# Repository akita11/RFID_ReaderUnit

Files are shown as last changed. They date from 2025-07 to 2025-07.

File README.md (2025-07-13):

# RFID Reader UNIT

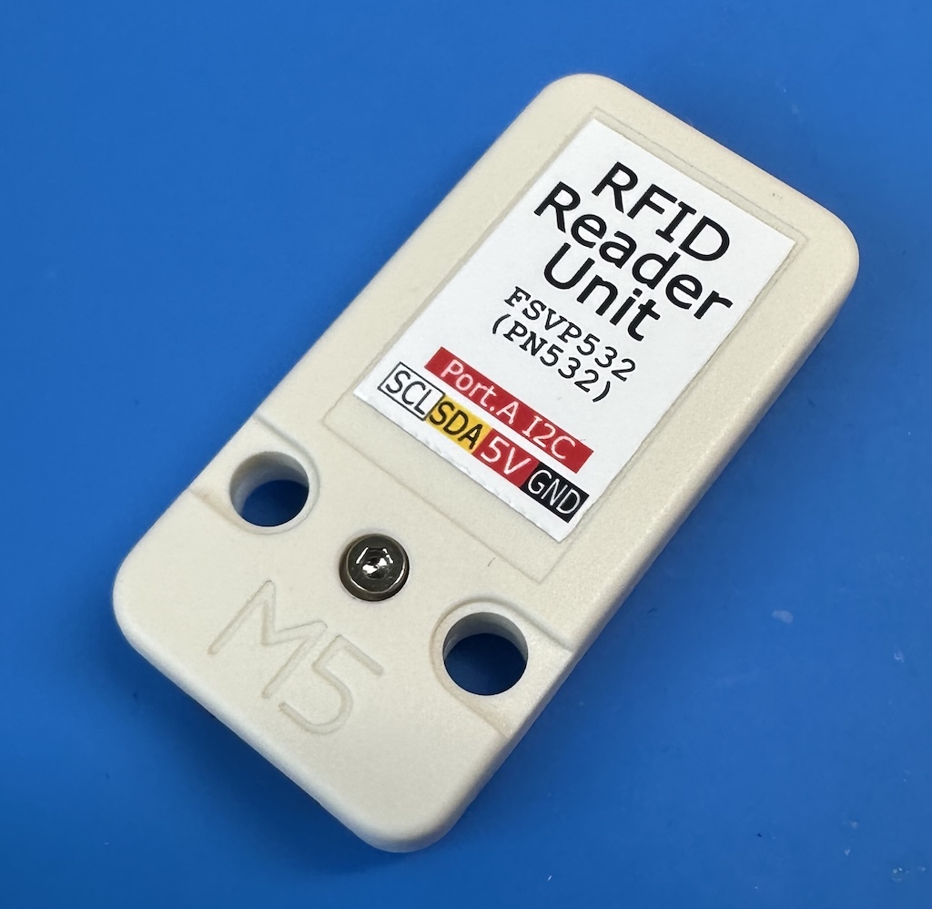
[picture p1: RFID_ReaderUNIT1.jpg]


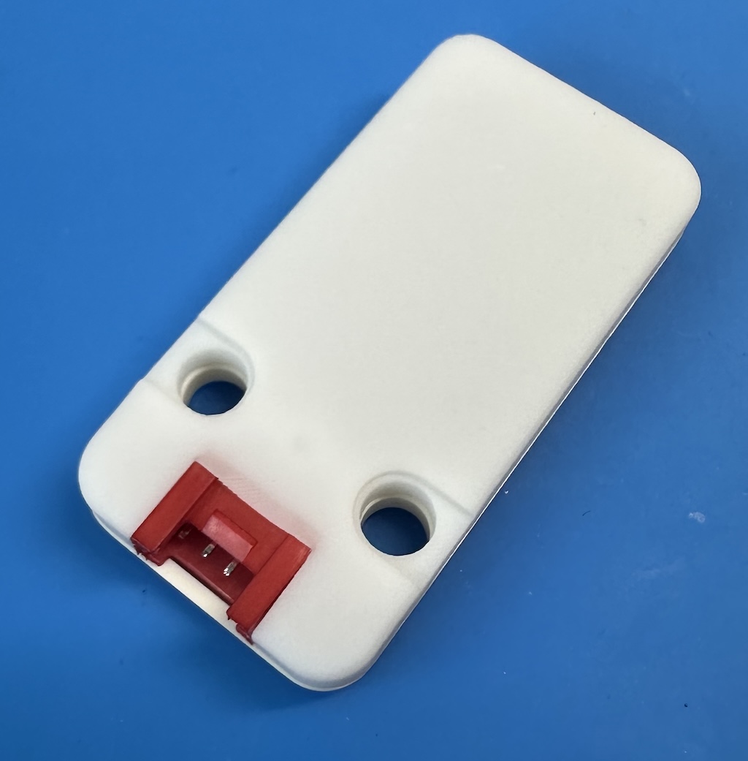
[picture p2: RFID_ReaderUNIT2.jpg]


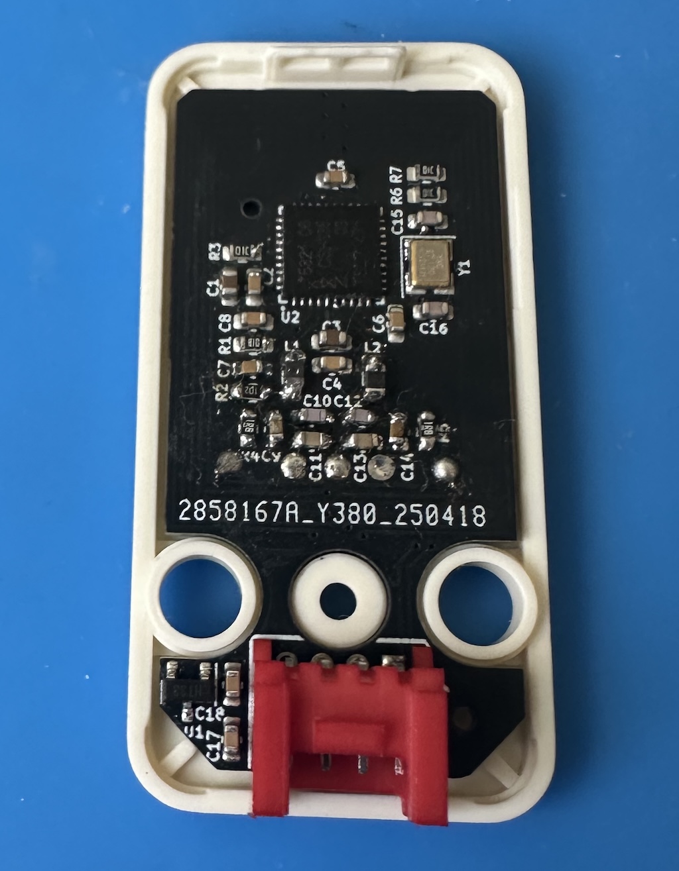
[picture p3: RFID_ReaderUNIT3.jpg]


## 内容

Felica対応のRFIDリーダICのForSinVe社FSVP532（よく使われるNXP社のPN532互換）を使ったRFIDリーダです。M5Stack等のマイコンとGroveケーブル（I2C通信）で接続して、FelicaやNFCを読み書きすることができます。PN532用のライブラリで使用することができます。（UIFlow用のカスタムブロックを用意する予定）

## 使い方

ArduinoやM5Stack等のマイコンにGroveポート経由でI2C接続します。
ソフトウエアはは、PN532用のもの使用します。
PN532用のソフトウエアとしては、Arduino用ライブラリがいくつかあります。
例えばAdafruitやSeeedのものがありますが、Felicaを読み出す関数とサンプルプログラムは提供されていないようです。
[こちら](https://github.com/elechouse/PN532)のライブラリは、これらを元にしたもの（fork）で、Felica関連の関数やサンプルプログラムも含まれているので、こちらを利用するとよいでしょう。
ただしサンプルプログラムは、PN532をI2C接続して使用する設定にはなっていませんので、冒頭の以下の「※」のところを変更します。これにより、I2C接続で使用できるようになります。
```FeliCa_card_read.pde
#if 0 // <--- ※original:1
  #include <SPI.h>
  #include <PN532_SPI.h>
  #include <PN532.h>

PN532_SPI pn532spi(SPI, 10);
PN532 nfc(pn532spi);
#elif 0
  #include <PN532_HSU.h>
  #include <PN532.h>

PN532_HSU pn532hsu(Serial1);
PN532 nfc(pn532hsu);
#else
  #include <Wire.h>
  #include <PN532_I2C.h>
  #include <PN532.h>

PN532_I2C pn532i2c(Wire);
PN532 nfc(pn532i2c);
#endif
```

なお稀に電源ON時のリセット(POR; Power On Reset)が効かず、初期化に失敗することがあるようです。その場合は、電源を入れなおしてください。

## 電波関連法令の規格について

RFIDリーダは無線通信機器ではなく「誘導式読み書き通信設備」というカテゴリに含まれます。
そのため、無線通信機器の認証に必要な、いわゆる技適は無関係です。
（[法令関連の情報まとめの例](http://dsas.blog.klab.org/archives/2018-04/52291765.html)）
「誘導式読み書き通信設備」は、法令の要件（電界強度の規定、または総務大臣型式指定）を満たせば許可不要で使用することができる、と規定されています。
その要件のうちの「電界強度の規定」（3mの距離における電界強度が500μV/m（≒54dBμV/m）以下）を満たしていることの表示方法については明記されていません。
そのため、測定条件や測定データ等の客観的なデータを示すことで、その要件を満たす、というのが一般的な解釈と考えています。
例えば（株）スイッチサイエンスで販売している[RFID2 Unit](https://www.switch-science.com/products/8301)では、電界強度の測定法・測定結果を示し、それに基づいて規定を満たしている、と表示しています。

このRFID Reader UNITの電界強度測定の測定法・測定結果は「RFID_ReaderUNIT_meaasure.pdf」に記載の通り、これは法令の要件である電界強度の規定を満たしています。
なお今回のアンテナ設計手順をまとめた資料は、AntennaDesign/以下にあります。

## Author

Junichi Akita (@akita11) / akita@ifdl.jp

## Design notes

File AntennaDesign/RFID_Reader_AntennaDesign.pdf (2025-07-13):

## RFID Reader Unit アンテナ設計と特性測定の記録

250710 akita11(akita@ifdl.jp)

⽬標
Felica も読める RFID リーダをつくって販売したい（M5Stack の RFID2 Unit は Felica は対応していな い）。AliExp などで売っているものもある（Arduino ⽤ライブラリなどもある）が、⽇本の電波法令の基 準を満たしているかが表⽰されていない。また形状も M5Stack の Unit サイズにしたい。 そこで、Felica を読める IC を使って Unit サイズのものを設計し（マイコンとの通信は I2C）、⽇本の電 波関連法令の基準を満たしていることを⽰したうえで販売したい。
なお 13.56MHz RFID の規格が歴史的経緯から複雑だが、⼤まかには以下の通り。なおよく使われている NXP の PN532 は、ISO/IEC14443-3 TypeA/B, MIFARE, Felica に対応しているので、これを使うことに する（正確にはその互換品の Forsinve 社 FSVP532 を使う）。
l ISO/IEC14443-3
Ø Type A: MIFARE など（NFC-A とも呼ばれる）
Ø Type B: マイナンバーカード、⽇本のパスポートなど（NFC-B とも呼ばれる）
l MIFARE：ISO 14443 Type A を拡張した NXP 独⾃規格。⽇本の交通系 IC カード。Classic, DESFire, Ultralight など複数シリーズが存在。
l FeliCa：ソニー独⾃規格（ISO 18092 準拠）、楽天 Edy、WAON、交通系 IC カードなど。（NFC−F とも呼ばれる）

RFID リーダのアンテナ設計の⼀般論
⼀次情報として、使う NXP 社から提供されている、PN532 のアプリケーションノート AN1445(”Antenna design guide for MFRC52x, PN51x and PN53x”)からはじめる。

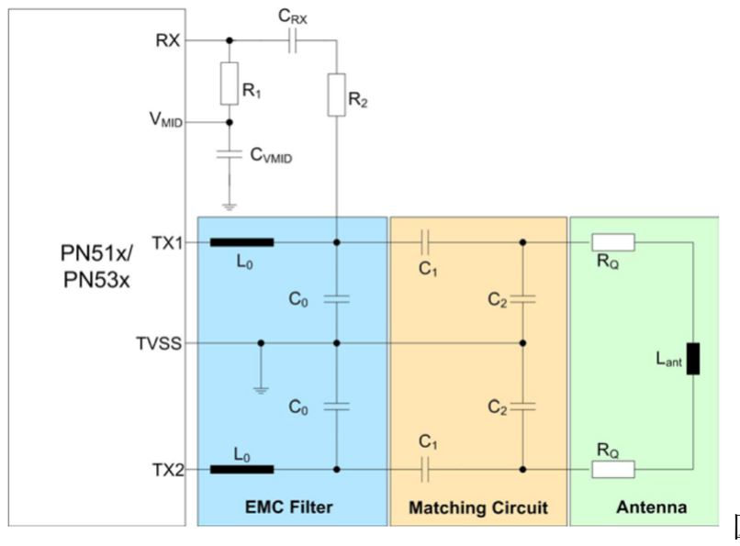
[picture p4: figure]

図 1
アンテナ部分は、EMS Filter 部、Matching Circuit 部、Antenna 部、からなる。
Antenna 部分は、基板パターンをぐるぐる巻いた配線パターン（ループアンテナ）で、まずはこれを設計

する。

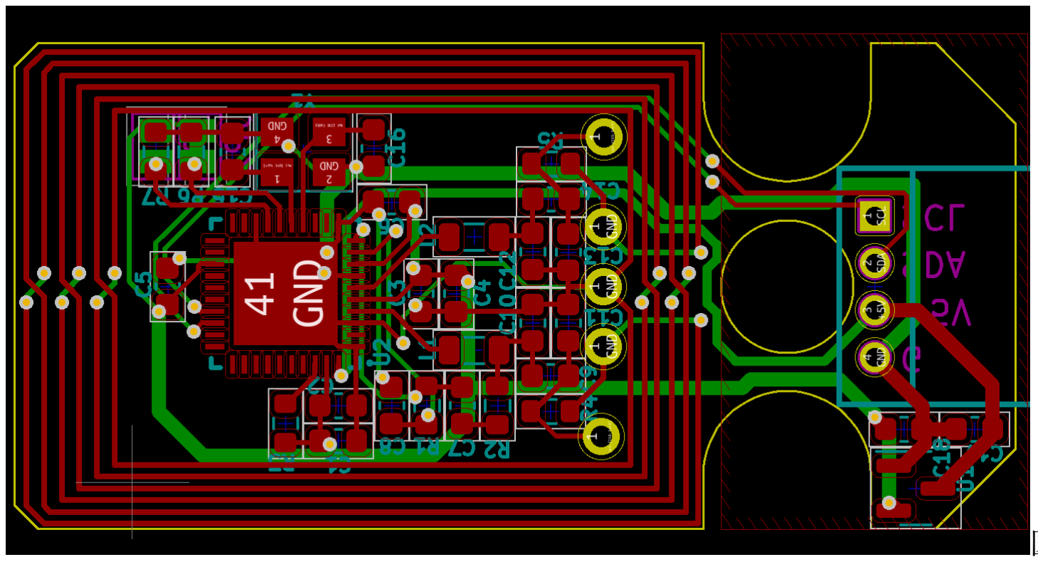
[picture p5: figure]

図 2
今回は、いろいろな事例を参考に、図 2 のような基板パターンを設計した。左側の外周部を 6 回まわっ ている配線パターンがインダクタになる。なお基板の素材や厚さ、配線幅や巻数からインダクタを計算 するツールもあるが、正直、その精度がどの程度あてになるかわからないので、今回は、まずは基板パタ ーンを設計し、それを実測することにした。
この基板を製造し、そのインピーダンス（等価回路）を計測し、それにあわせて図 1 の EMC Filer 部と Matching Circuit 部の素⼦値を決めていく。その後、計算（シミュレーション）と実測を⾏き来しながら、 ⽬的の特性になるような素⼦値を決定する。
なおこの AN1445 は、けっこう途中が省略されていて（例えば C1,C2 を変えるとどう特性が変わるか、 など、また L0 を 560nH で決め打ちしている（後述のようにこれは変更しないとマッチングがとれない）、 など）、こちらの別の RFID Reader ⽤ IC のアプリケーションノートを読むことで理解が深まり、マッチ ング調整の⽅針の⾒通しを⽴てることができた。
l AN12549（”PN5190 antenna design guide”）
l AN13219（”PN7160 antenna design and matching guide”）
また素⼦値の計算はまあまあ⾯倒な式で、それを計算するための Excel シート（AN144411.xls）が AN1445 で紹介されて提供されているので、それを使ってもいいと思う。ただ個⼈的には、これの計算過程に出て くる等価回路が 2 種類あって、並列等価回路の Ra の計算・求め⽅がわからなかったため、結果としてあ まり使わなかった。逆に今回は、別の IC ⽤の「PN7160_matching_calculator.xls」がかなり使えた（ただ これが NXP 公式サイトでは⾒つからず、どこかのオンラインフォーラムでみつけた）。

インピーダンスアナライザでのアンテナ等価回路の測定

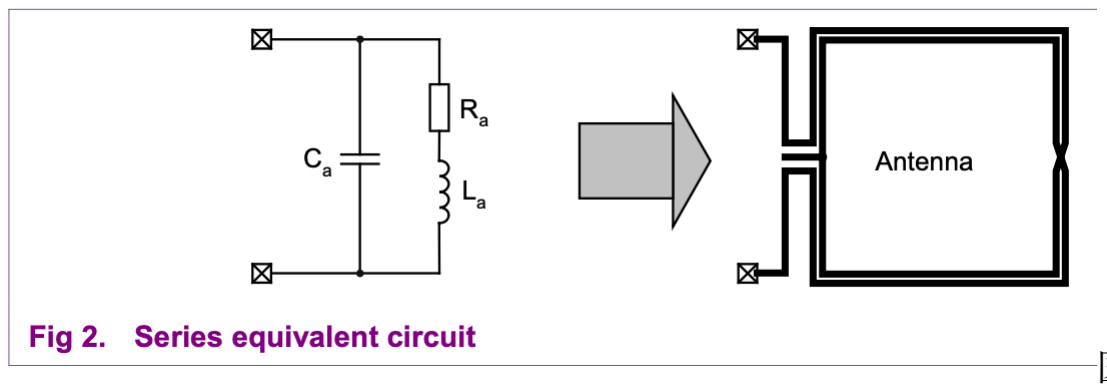
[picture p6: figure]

図 3

AN1445 では、インピーダンスアナライザまたな VNA（Vector Network Analyzer）でアンテナ（ループ アンテナ）の等価回路を求める⼿順が⽰されている。そこで HIOKI のインピーダンスアナライザ (IM7580A)で、図 3 の等価回路を求めた。ただ結論から⾔うと、この等価回路パラメータがどの程度正 確かがよくわからず、結果として後述の NanoVNA を使ってすべての計測は⾏った。なお計測前の計測 器の校正（Open/Short/Load：後述）は⾏うべき。

NanoVNA でのアンテナ等価回路の測定
NanoVNA とは
AN12810（”How to use the NanoVNA for the NFC reader antenna design”）に、使ってアンテナマッチ ングに NanoVNA をどう使うか、について書かれている。NanoVNA は、オープンソースな⼩型 VNA で、 スイッチサイエンス等で買える。VNA は、周波数を変えたときの特性（インピーダンス）やスミスチャ ートを書くことができ、PC につないでグラフを⾒たり保存したりすることもできる。この AN12810 で は、簡易的な計測法としてピンヘッダ・ソケットを使う⽅法が紹介されており、この⽅法でも⼗分に計 測・設計を⾏うことができた。とりはずしがしやすいので、L や C を変更しながら特性を測る、という 作業が捗る。
スミスチャート
⾼周波回路の話で必ずといっていいほどよく出てくるスミスチャートについては、事前にこちらの記事 で勉強しておいた。
https://www.wti.jp/contents/ts-blog/190613.htm
周波数によって LC のインピーダンス（リアクタンス）が変化するが、スミスチャートは、それが周波数 とともにどう変化するか、を理解しやすい図。主な特徴は以下。
l LCR 回路に R を直列に追加すると、リアクタンスは変化しないので、全体のインピーダンスは「等 リアクタンス円」上を移動する
l LCR 回路に LC を直列に追加すると、抵抗分は変化しないので、全体のインピーダンスは「等抵抗 円」上を移動する。
l 中央が 50Ω+j0（50Ω抵抗のみ）。
l ⼀般には⽬標周波数でのインピーダンスを 50Ω にしたいので、R または LC を直列追加して両円に 沿ってインピーダンスを移動させて、50Ωにもっていく。
l R や LC を並列接続する場合は、アドミッタンスチャートを使う。

NanoVNA の校正
⼀般にインピーダンスを計測するときには、計測に使うケーブル・コネクタに、(1)Short（短絡）、(2)Open （開放）、(3)Load（負荷）の 3 種類の負荷を接続し、それが 0Ω・∞・50Ωになるように校正する。 AN12810 では、4p ピンソケットと 100Ωチップ抵抗 2 個を使って、この 3 種類の負荷を繋げる⽅法が紹 介されているので、これをつくり、それを使って校正する。

アンテナ等価回路の算出
まずループアンテナ（等価回路の RQの右側）に 2p ピンソケットをとりつけ、NanoVNA で、10MHｚ〜

30Mz の範囲でで、スミスチャートと Z（R と jX）を計測する。（なお RFID の中⼼周波数は 13.56Mz） スミスチャート上のマーカを移動させ、13.56MHz 付近での R と X を求める。この周波数では、コンデ ンサのリアクタンスは⼗分⼤きくてほぼ無視できるため、図 3 の等価回路の Caを求めることはできない。 この周波数での X はほぼインダクタンスのリアクタンスなので、それから La を求めることができる （NanoVNA では L も表⽰もできる）。同様に Raも求められる。なおこのときは、ほぼインダクタを計測 していることになるので、スミスチャートは、おおままには図 4 の⾚線のあたりにくる（ほぼ誘導性の 純リアクタンス）。

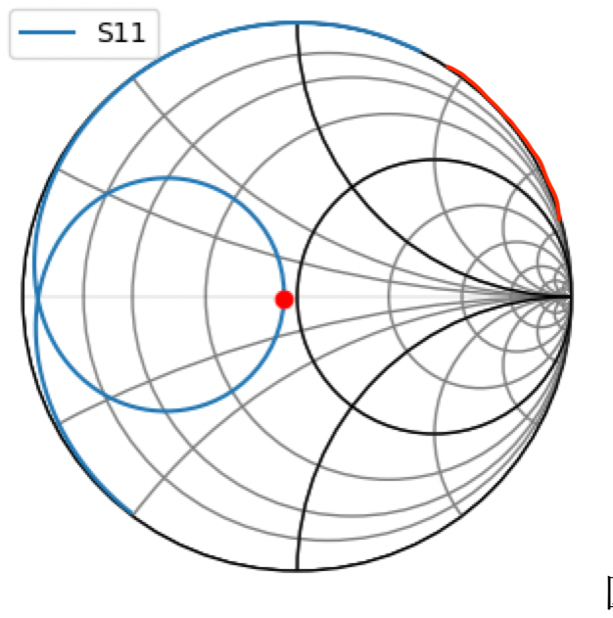
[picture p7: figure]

図 4

図 3 の Ca の計測は、試⾏錯誤の結果、あまり正確ではないかもしれないが、ピンセット型 LCR メータ を C 計測モードとしてループアンテナに接触させて計測した。 以上の⼿順での計測結果は以下の通り。
l Ra = 4.03[Ω]
l La = 1.581[uH]
l Ca = 9.43[pF]
なおアンテナに直列につなぐ２個の RQは 、アンテナの Q 値（共振の鋭さ）を適切な値（35 程度）とす るために、AN1445 の⼿順で求める。今回の場合は、計算したところ、RQ=0Ωで⼤丈夫そうだった。

スミスチャートのシミュレーション
このループアンテナの等価回路に対して、EMI Filter 部と Matching Circuit 部の L0, C0, C1, C2を求める のに進む。ただこれらの値のアタリをつけたいのと、それぞれの値を変化させたときに、スミスチャート と Z（実部と虚部）がどう変化するかの傾向を知りたかったので、ChatGPT を使いながら、インピーダ ンスとスミスチャートを計算するプログラム(match.py)を作成し、傾向をつかんだ。ちなみに C0 は、 AN1445 などから、EMI Filter 部の共振周波数 fc0=1/2π√(L0C0) = 14.3MHz となるように求める。 AN1445 などには以下のような調整法が書いてあり、この傾向は、この match.py でも確認できる。 l C1：共振点でのインピーダンス（スミスチャートの⼀回りループの⼤きさ）。⼩さいほどインピーダ ンスが⼩さくなる。
l C2：共振点の位置。スミスチャート上の f=13.56MHz 点の位置を決める。

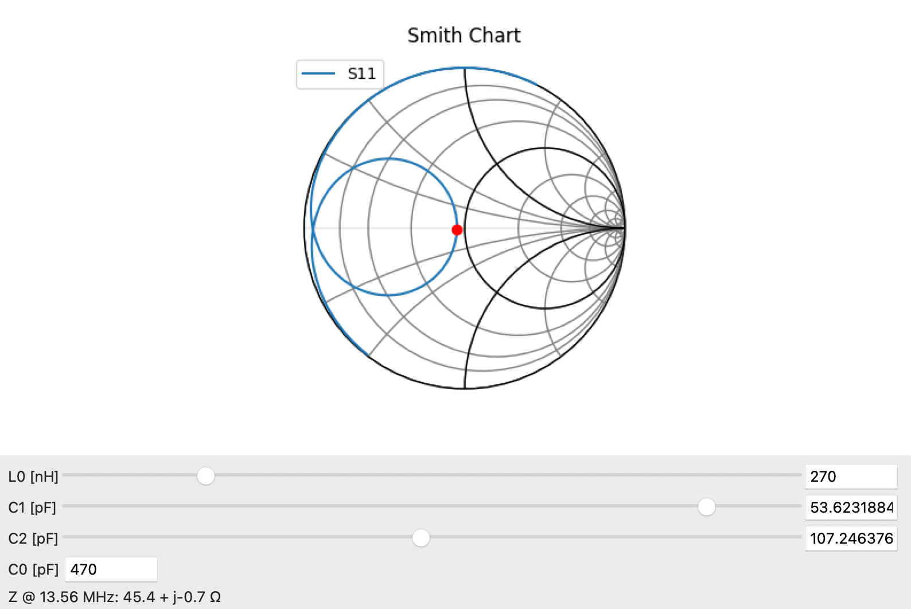
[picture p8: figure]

図 5

AN1445 などから、⽬標は以下の通りに設定する。

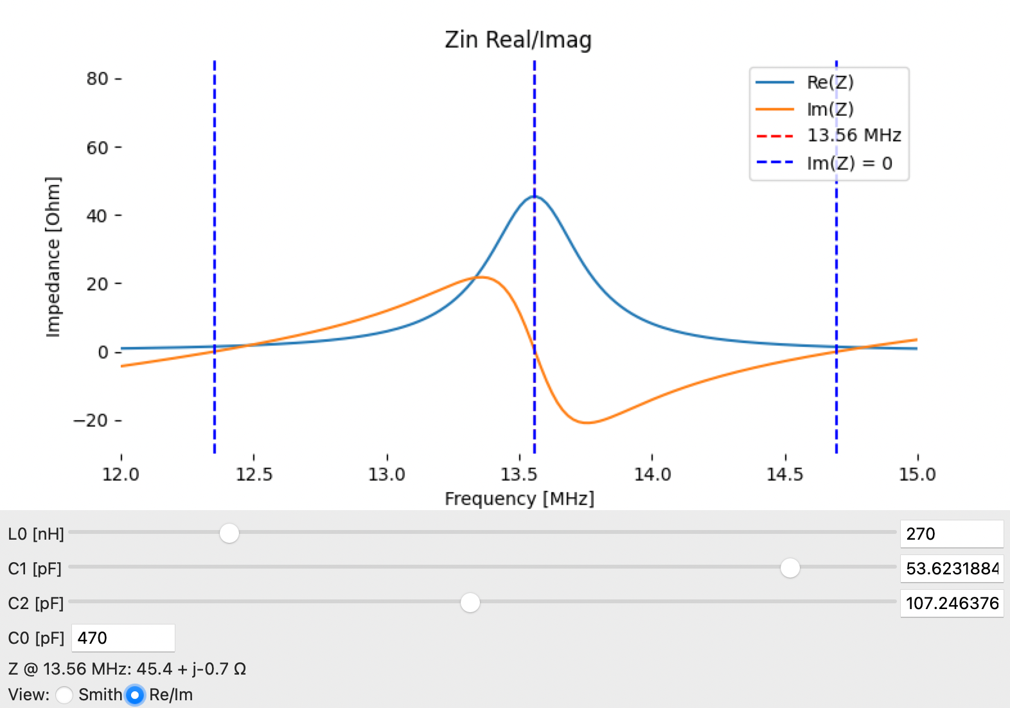
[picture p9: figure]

l スミスチャート：13.56MHz を中⼼に上下が対称となるように、ぐるりと⼀回りする。13.56MHz（上 ⼿の⾚点の位置）でのインピーダンスは 40〜50Ω（これは実軸上に来るはずで、その等抵抗円の値 から求める。ちなみにスミスチャートの中⼼は 50Ω）。
l インピーダンス：上記のスミスチャートは、Z の実部・虚部のグラフでは、13.56MHz で実部がピー ク(40〜50Ω)、虚部が 0 となる。またこの 13.56MHz を中⼼に左右が対称となるように。 これから、L0=270nH（これから C0=470pF となる）、C1=56pF、C2=110pF あたりが妥当そうと⽬星を つけることができた。そのときのスミスチャートとインピーダンスは図 5 のとおり。

実デバイスのアンテナインピーダンス測定
上記の素⼦値の L, C, R をループアンテナ基板に実装する。なおインダクタはなるべく巻線抵抗が⼩さい ものを選ぶ（今回は 0806 サイズのチップ巻線インダクタ）。またセラミックコンデンサには、材料と温 度特性からは⼤きく以下の 2 種類があるが、今回は容量が 100pF 程度と⼩さいため、温度特性の⼩さい C0G 型を使う。なお特性のマッチング調整のために、少しずつ R や C の値を変化させる（取り替えて試 す）ことが多いので、いわゆる「サンプル本」が⼿元にあると安⼼。例えば 0603 サイズの各種セラミッ クコンデンサが 100 種類（各 50 個程度）ぐらいのものが AliExp などで 2000 円くらいで売っている。 l Class I (C0G/NPO): ⼩容量だが、温度変化に対する静電容量の変化が⼩さい
l Class II (X7R, X5R など): ⼤容量だが、温度変化による静電容量の変化が⼤きい
この状態で、IC の TX1/2 端（L0 の IC 側の 2 端⼦）のインピーダンスを NanoVNA で計測する（IC も 実装した状態の⽅が良い）。その結果は図 6 のとおり。緑⾊の線がスミスチャートで、実軸に対して対称 ではないが、f=13.56MHz でのインピーダンスが 50Ω程度（リアクタンスはほぼ 0）であることが確認 できる。またインピーダンスの実部（⽔⾊）と虚部（紫⾊）も、ほぼ実部がピーク・虚部が 0 となる共振 点が 13.56MHz 付近にあり、共振に対してほぼ左右対称になっていることが確認できる。

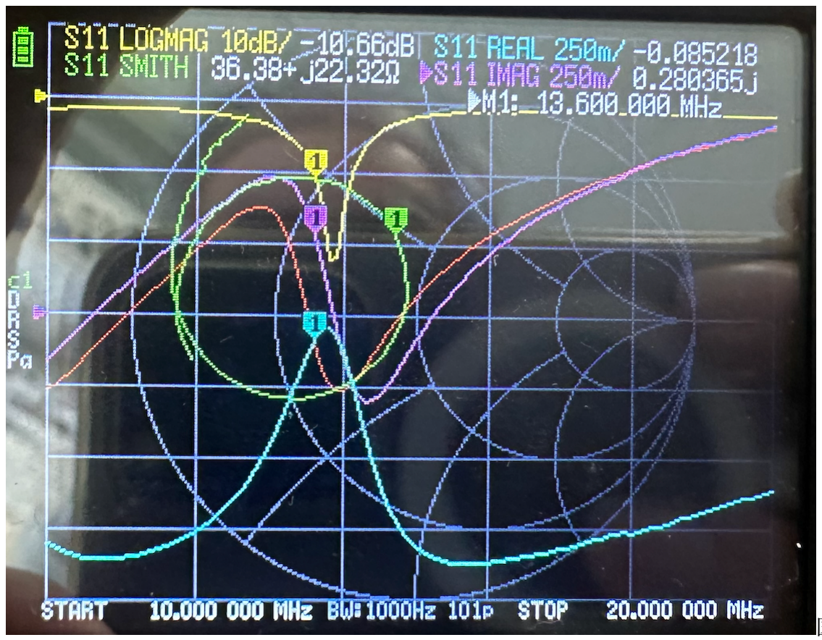
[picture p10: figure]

図 6

受信回路の設計
AN1445 の⼿順にそって、受信回路側の素⼦値を決める。まず R1=1kΩ、CRX=1nF、CVMID=100nF とす る。その後、R2 を決めるための⼿順が AN1445 に書いてあり、アクティブプローブを使って RX 端⼦で の電圧を測ることになっている。今回は eBay で購⼊した半 DIY のアクティブプローブを購⼊して、そ れをオシロに繋いで波形を観測したが、その校正（計測値と実際の値との対応）がいまいちわからず、他 の PN532 ボードで同⼀箇所の電圧を計測して、同程度となるように R2 を決定した。結果として、他の PN532 ボードと同じ R2=1kΩで⼤丈夫そうと判断できた。

実デバイスの動作
Arduino に I2C 接続し、PN532 ⽤ライブラリの読み出し⽤サンプルプログラムを書き込んで動作テスト を⾏った。なお PN532 ⽤のライブラリはいくつかあるが、Adafruit や Seeed のものは Felica 読み出しの サンプルが⼊っていない。これらから fork している、こちらのライブラリ（実は AliExp などでよく⾒か ける⾚⾊正⽅形の PN532 ボードのメーカ）が、Felica 読み出しのサンプルが⼊っているので、こちらを 使うのがよい。
https://github.com/elechouse/PN532
適当な Felica をかざし、読み出しができることを確認した。なおアンテナに多少⼤きな電流を流すため に、IC が多少発熱する。（アンテナのマッチングが不完全だとこの発熱が⼤きい）

電波関連法令と放射電界強度の測定
今回の 13.56MHz を使う RFID リーダは、WiFi 機器や Bluetooth 機器のような無線通信機器ではなく、 「特定無線設備」の中の「誘導式読み書き通信設備」というカテゴリに含まれる。そのため、無線通信機 器の認証に必要な、いわゆる技適は無関係。（電波法施⾏規則 44 条第 2 項第 2 号（許可を要しない通信 設備‐誘導式読み書き通信設備）
参考（法令関連の情報まとめの例）http://dsas.blog.klab.org/archives/2018-04/52291765.html

「誘導式読み書き通信設備」は、法令の要件（電界強度の規定、または総務⼤⾂型式指定）を満たせば許 可不要で使⽤することができる、と規定されている。その要件のうちの「電界強度の規定（500μV/m（約 54dBμV/m）以下）」を満たしていることの表⽰⽅法については明記されていない。そのため、測定条件 や測定データ等の客観的なデータを⽰すことで、その要件を満たす、というのが⼀般的な解釈と考えら れる。例えば取れば（株）スイッチサイエンスで販売している RFID2 Unit ( https://www.switch-science.com/products/8301 )では、製品紹介ページに電界強度の測定法・結果を掲載してあり、それに基 づいて規定を満たしている、と表⽰している。
実際の使⽤には、EMI（電磁輻射）計測装置で RFID Reader UNIT の電界強度を測定し、この要件を満 たしていることを確認する必要がある。今回のものの測定結果は、”RadioTestReport.pdf”に掲載してあ る。

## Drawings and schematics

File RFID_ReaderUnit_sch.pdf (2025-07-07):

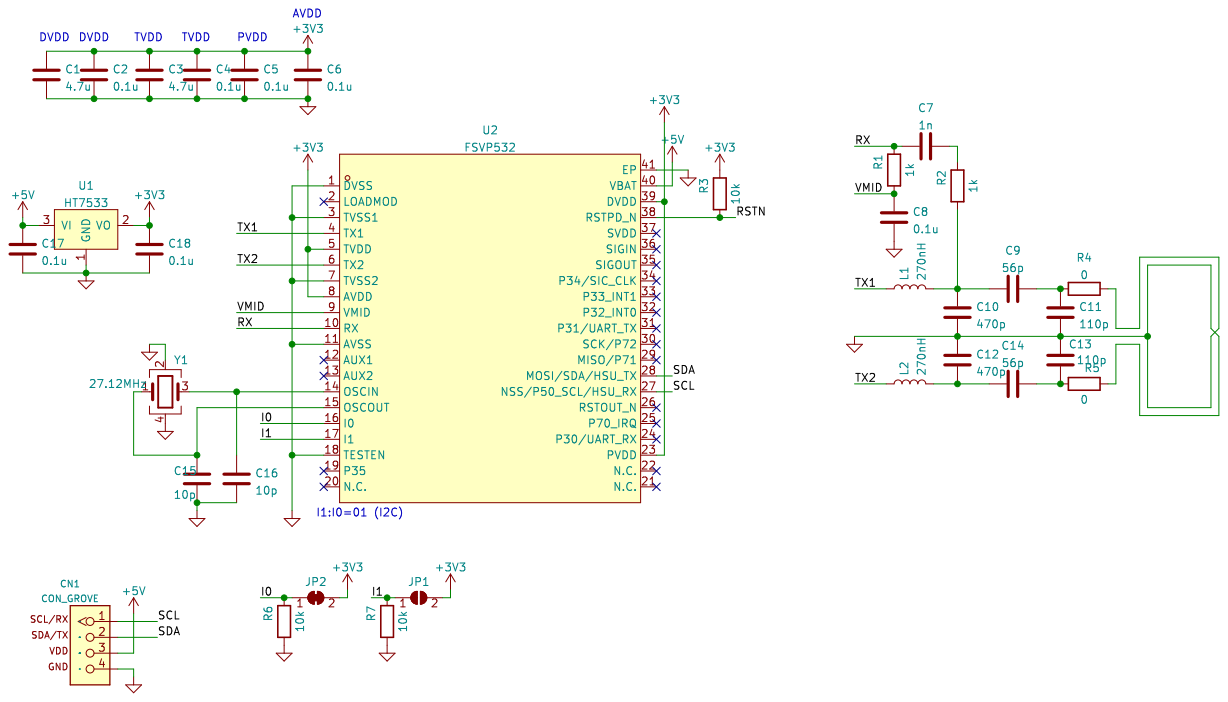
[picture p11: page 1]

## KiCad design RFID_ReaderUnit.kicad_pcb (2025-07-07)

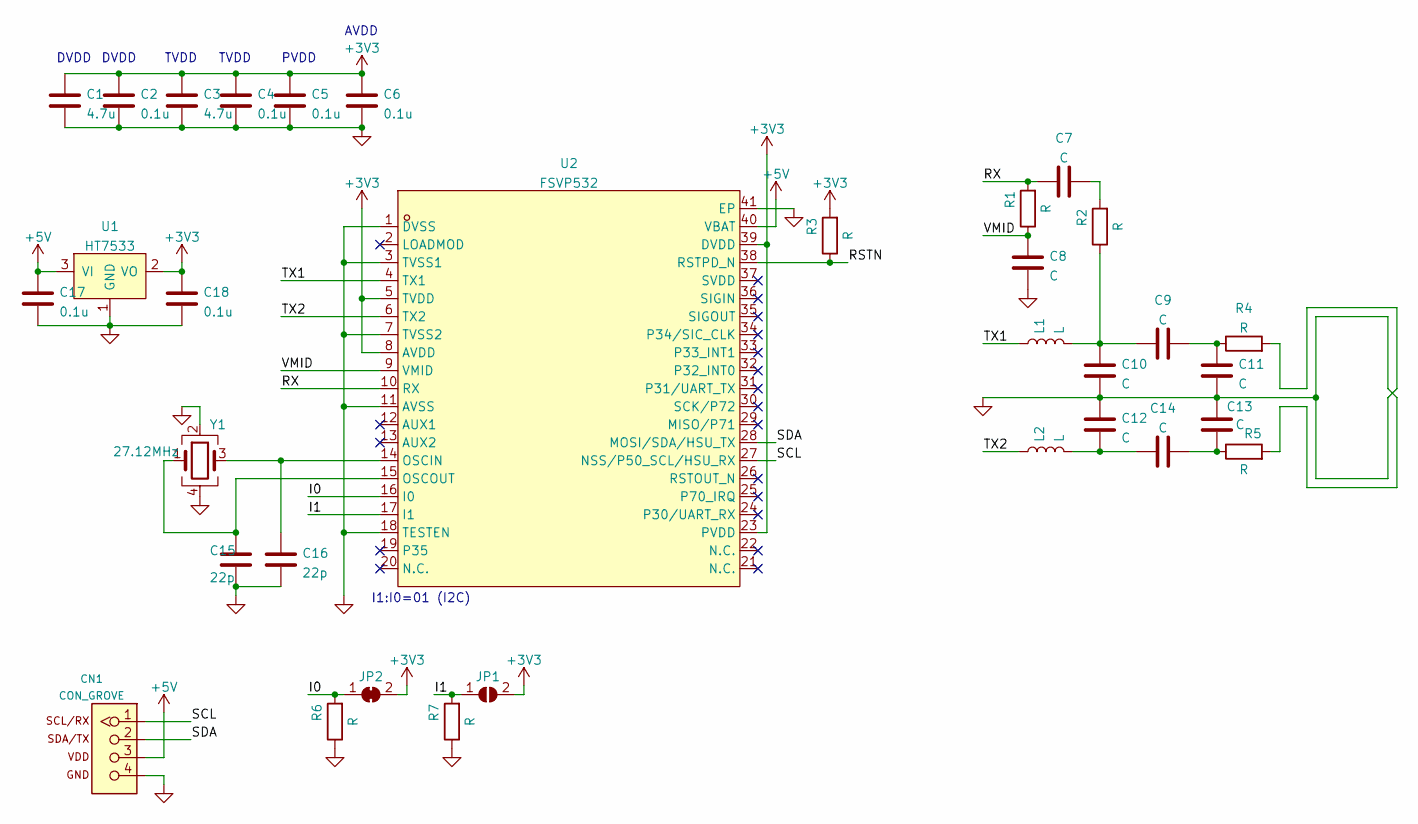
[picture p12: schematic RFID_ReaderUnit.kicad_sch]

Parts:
C1, C3: 4.7u; C_0603_1608Metric
C2, C4, C5, C6, C17, C18: 0.1u; C_0603_1608Metric
C7, C8, C9, C10, C11, C12, C13, C14: C; C_0603_1608Metric
C15, C16: 22p; C_0603_1608Metric
CN1: CON_GROVE; CON_GROVE_H
JP1: SolderJumper_2_Open; SolderJumper-2_P1.3mm_Open_Pad1.0x1.5mm
JP2: SolderJumper_2_Bridged; SolderJumper-2_P1.3mm_Bridged_Pad1.0x1.5mm
L1, L2: L; L_0805_2012Metric
R1, R2, R3, R4, R5, R6, R7: R; R_0603_1608Metric
U1: HT7533; SOT-23; LCSC C5136781
U2: FSVP532; QFN-40_L6.0-W6.0-P0.50-TL-EP4.4; LCSC Part C5336464
Y1: 27.12MHz; Crystal_SMD_3225-4Pin_3.2x2.5mm

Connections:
+3V3: C1.1, C2.1, C3.1, C4.1, C5.1, C6.1, C18.1, JP1.2 (B), JP2.2 (B), R3.2, U1.2 (VO), U2.5 (TVDD), U2.8 (AVDD), U2.23 (PVDD), U2.39 (DVDD)
+5V: C17.1, CN1.3, U1.3 (VI), U2.40 (VBAT)
/I0: JP2.1 (A), R6.2, U2.16 (I0)
/I1: JP1.1 (A), R7.2, U2.17 (I1)
/RSTN: R3.1, U2.38 (RSTPD_N)
/RX: C7.1, R1.2, U2.10 (RX)
/SCL: CN1.1, U2.27 (NSS/P50_SCL/HSU_RX)
/SDA: CN1.2, U2.28 (MOSI/SDA/HSU_TX)
/TX1: L1.1, U2.4 (TX1)
/TX2: L2.1, U2.6 (TX2)
/VMID: C8.2, R1.1, U2.9 (VMID)
GND: C1.2, C2.2, C3.2, C4.2, C5.2, C6.2, C8.1, C10.2, C11.2, C12.1, C13.1, C15.2, C16.2, C17.2, C18.2, CN1.4, R4.2, R5.2, R6.1, R7.1, U1.1 (GND), U2.1 (DVSS), U2.3 (TVSS1), U2.7 (TVSS2), U2.11 (AVSS), U2.18 (TESTEN), U2.41 (EP), Y1.2, Y1.4
unnamed: C7.2, R2.2
unnamed: C9.1, C10.1, L1.2, R2.1
unnamed: C9.2, C11.1, R4.1
unnamed: C12.2, C14.1, L2.2
unnamed: C13.2, C14.2, R5.1
unnamed: C15.1, U2.15 (OSCOUT), Y1.1
unnamed: C16.1, U2.14 (OSCIN), Y1.3

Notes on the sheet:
TVDD
PVDD
DVDD
AVDD
I1:I0=01 (I2C)

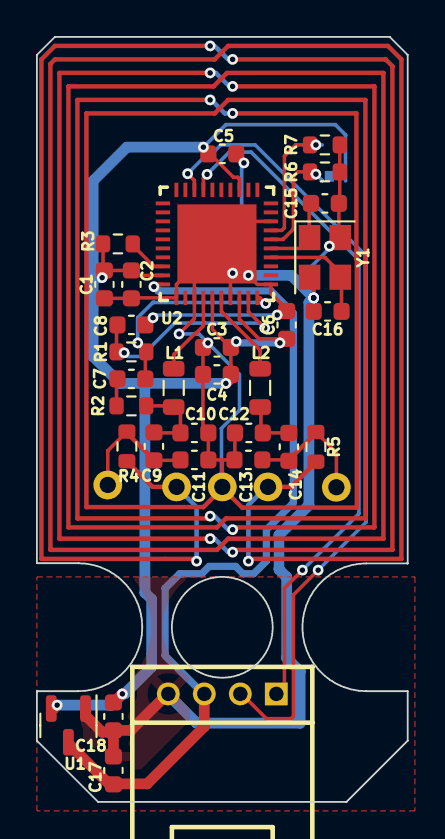
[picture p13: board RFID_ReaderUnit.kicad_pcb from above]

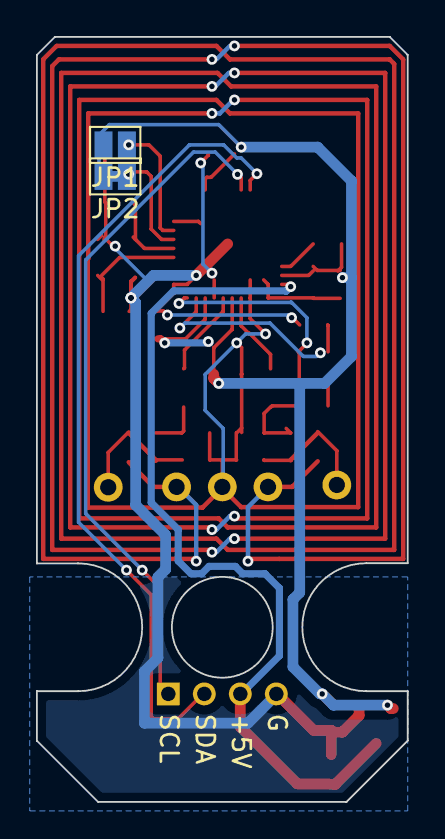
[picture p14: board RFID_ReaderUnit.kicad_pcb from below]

Board: 2 copper layers, 20.6 x 42.5 mm, 33 parts (2 on the bottom side), 19 nets.
